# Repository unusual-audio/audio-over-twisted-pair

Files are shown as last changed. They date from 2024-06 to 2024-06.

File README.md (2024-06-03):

# Simple audio over twisted pair adapter

A basic adapter box that can route 4 differential audio signals on TRS connectors over twisted pair cable (ideally S/FTP).




## Bill of materials (per unit)

- 1× Main PCB ([gerber files](https://github.com/unusual-audio/audio-over-twisted-pair/releases/download/revision1/PCB.zip))
- 1× Front panel PCB ([gerber files](https://github.com/unusual-audio/audio-over-twisted-pair/releases/download/revision1/Front.Panel.zip))
- 1× Rear panel PCB ([gerber files](https://github.com/unusual-audio/audio-over-twisted-pair/releases/download/revision1/Back.Panel.zip))
- 1× [Adafruit 2230](https://www.mouser.de/ProductDetail/485-2230) enclosure
- 1× [Amphenol RJHSE-5380](https://www.mouser.de/ProductDetail/523-RJHSE-5380) RJ45 connector
- 4× [Neutrik NRJ6HF](https://www.mouser.de/ProductDetail/550-20311) TRS connector
- 4× [Neutrik NRJ-NUT-B](https://www.mouser.de/ProductDetail/550-1005) nut for TRS connector
- 8× M2.5x7 machine screw (Adafruit supplies counterunk screws, unsuitable for PCB panels)
- 4× Self-adhesive rubber feet (e.g. 3M Bumpons SJ 5076)

## Caveats

- This is a hobby project. Recreate at your own risk. (but if you do, send pictures to <unusualaudio@protonmail.com>)
- These are not necessarily compatible with similar commercial products as the wiring is not standardised.

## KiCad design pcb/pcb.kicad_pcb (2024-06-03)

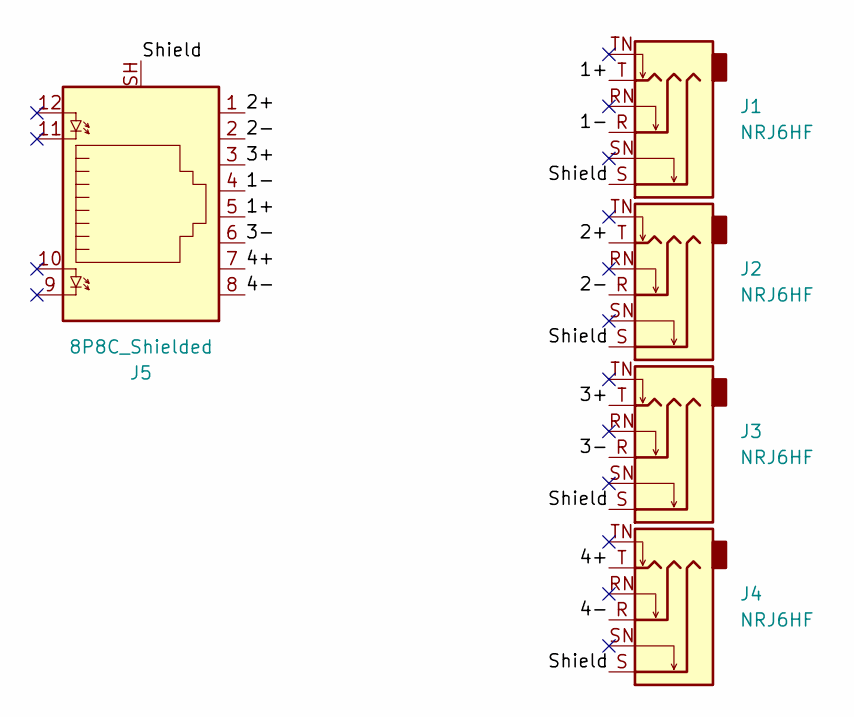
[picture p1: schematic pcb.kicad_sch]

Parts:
J1, J2, J3, J4: NRJ6HF; Jack_6.35mm_Neutrik_NRJ6HF_Horizontal_No_Outline
J5: 8P8C_Shielded; RJ45_Amphenol_RJHSE538X

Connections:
/1+: J1.T, J5.5
/1-: J1.R, J5.4
/2+: J2.T, J5.1
/2-: J2.R, J5.2
/3+: J3.T, J5.3
/3-: J3.R, J5.6
/4+: J4.T, J5.7
/4-: J4.R, J5.8
/Shield: J1.S, J2.S, J3.S, J4.S, J5.SH

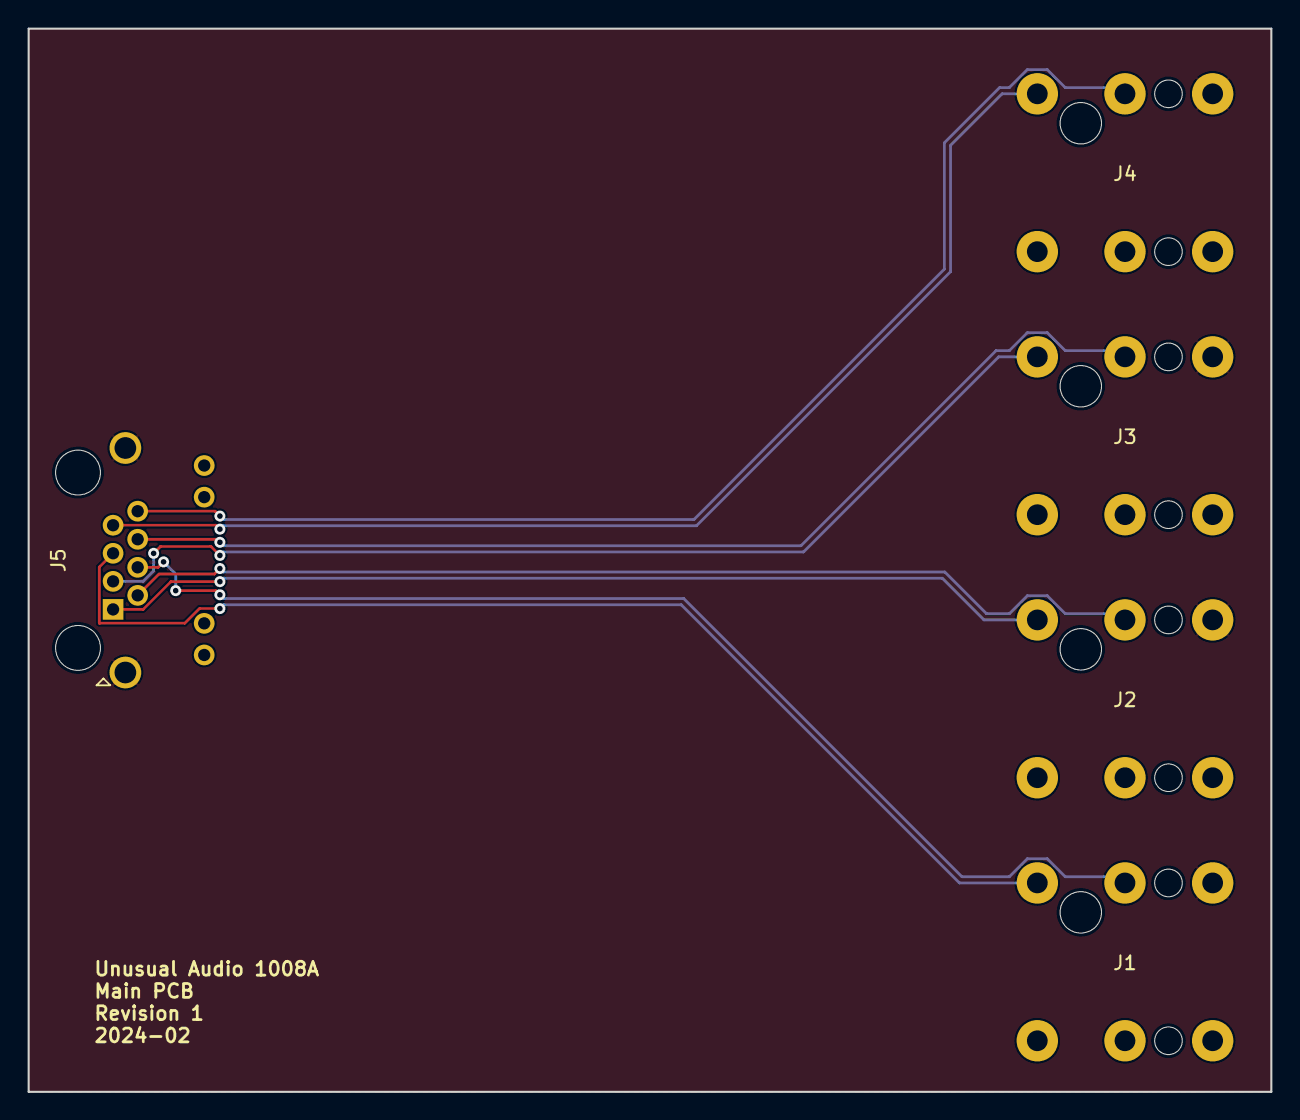
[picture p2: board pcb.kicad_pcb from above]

Board: 2 copper layers, 90.0 x 77.0 mm, 5 parts (0 on the bottom side), 9 nets.
